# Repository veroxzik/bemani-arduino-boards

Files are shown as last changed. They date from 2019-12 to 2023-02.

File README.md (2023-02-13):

# bemani-arduino-boards
 A collection of Arduuino breakout boards and code for Bemani uses.

## How to Order

Download the *.zip file from your chosen Boards/gerbers folder and upload to your PCB manufacturer of choice. JLCPCB is a common suggestion and the one I use most frequently. Default choices are all acceptable.

A list of parts for each board is located in their respective folders.

## Physical Settings on the Boards

Each board has a few physical solder jumpers that you must set before use.

### Setting the lights power source

Locate the jumper labeled CNR PWR | USB PWR. If you wish to power the lights off of USB power, jump the center pad and the USB PWR pad together.

If you wish to use the external power header, jump the center pad and the CNR PWR pad together. All external power headers are such that the square pin is positive.

On several boards, it is necessary to select whether you want to use encoders or buttons. Such option is used by soldering the *two* jumpers between either BUT or ENC.

On the Micro boards, if you use one encoder, it must be QE2. On the Pro Micro board, it must be QE1. (Or you can change my code if you don't like this restriction.)

## How to Flash Firmware

### Load the board profile

Move the folder `Additional Files\arduino-bemani` to your local hardware folder, most commonly located at `Documents\Arduino\hardware\`.
Your final path should look like `Documents\Arduino\hardware\arduino-bemani`.

Start the Arduino IDE / restart if it's already open.

This uses a copy of the Arduino 1.8.1 core, for reference. You should not have to update it.

### Loading the firmware

In the Arduino IDE, select the board using `Tools->Board->Bemani Controller (Micro/Pro Micro)` under the `VXZK Custom Boards` section.

In `Config.h`, set the following parameters per your board and setup.

```c
/* --- --- --- --- --- --- ---
   Frequently Changed Settings
   --- --- --- --- --- --- --- */

// This is the number of encoders you are using.
// If it is 1 and you are using a Micro board, then you must use QE2.
// If it is 1 and you are using a Pro Micro board, then you must use QE1
#define NUM_ENCODERS 0

// This is the PPR of your encoder
// Common values are 600 for Chinese encoders and 24 for Bourns encoders
const uint16_t pulseCount = 24;

// Uncomment the corresponding define for the microcontroller you are using
//#define USE_PROMICRO
//#define USE_MICRO
```

You must uncomment either the USE_PROMICRO or USE_MICRO define or the compiler will throw an error.

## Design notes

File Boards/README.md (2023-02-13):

# Board Selection

Use the following guide to help you figure out which board suits your purposes.

These boards are designed for quadrature encoders. They *do not* support potentiometers.

## Micro Breakout

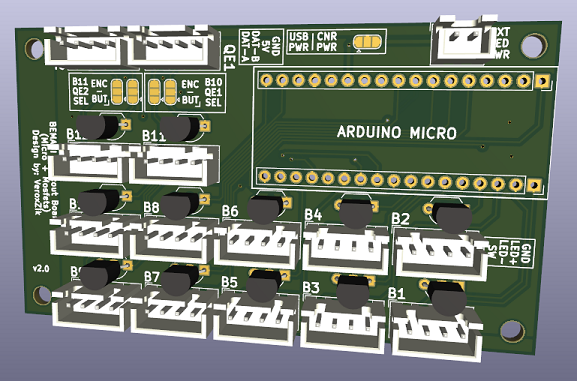
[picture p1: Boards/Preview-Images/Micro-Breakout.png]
Micro Breakout Board Image


This board uses the Arduino Micro as its base and supports 4 pin button connectors using the DJ DAO layout.

It is configurable for one of the three options:
1. 12 buttons, no encoders
2. 11 buttons, 1 encoder
3. 10 buttons, 2 encoders

## Micro Breakout + RGB

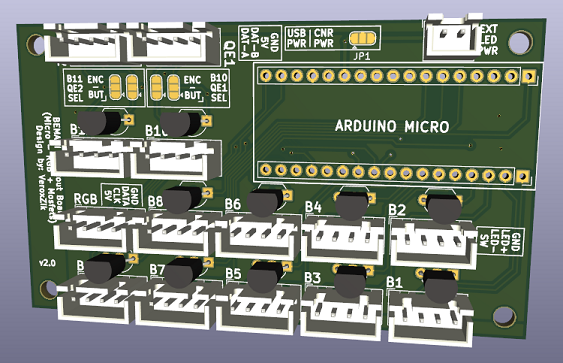
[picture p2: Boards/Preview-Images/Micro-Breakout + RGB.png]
Micro Breakout + RGB Board Image


This board uses the Arduino Micro as its base and supports 4 pin button connectors using the DJ DAO layout.

It is configurable for one of the three options:
1. 11 buttons, no encoders
2. 10 buttons, 1 encoder
3. 9 buttons, 2 encoders

In addition, there is a header for ARGB leds (WS2812B or APA102).

## ProMicro Breakout

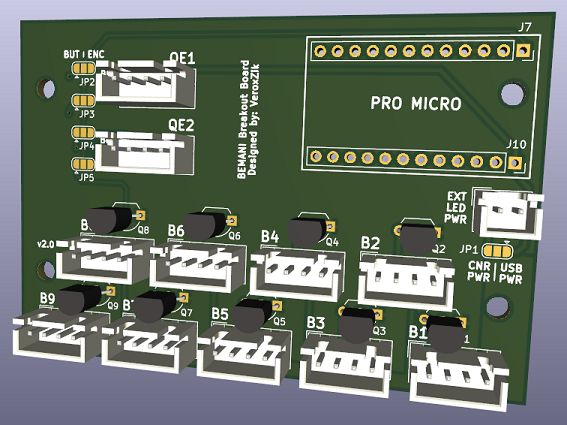
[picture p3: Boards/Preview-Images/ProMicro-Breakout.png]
ProMicro Breakout Board Image


This board uses the Sparkfun Pro Micro as its base and supports 4 pin button connectors using the DJ DAO layout.

It is configurable for one of the three options:
1. 9 buttons, no encoders
2. 8 buttons, 1 encoder
3. 7 buttons, 2 encoders

## ProMicro Breakout + RGB

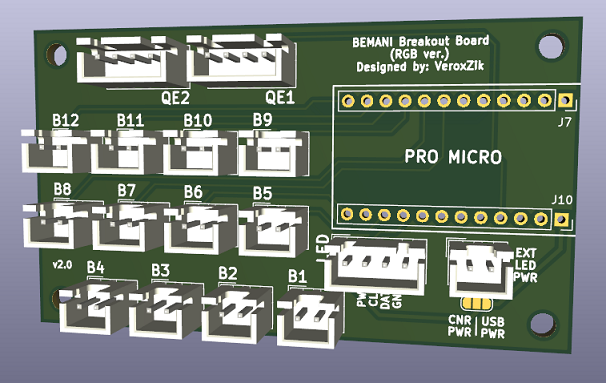
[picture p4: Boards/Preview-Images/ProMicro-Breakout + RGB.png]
ProMicro Breakout + RGB Board Image


This board uses the Sparkfun Pro Micro as its base and supports 2 pin buttons. It does not support button LEDs.

It supports 12 buttons and 2 encoders.

In addition, there is a header for ARGB leds (WS2812B or APA102).

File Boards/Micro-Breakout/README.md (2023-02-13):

# Micro Breakout

Micro Breakout Board Image

## Description

This board uses the Arduino Micro as its base and supports 4 pin button connectors using the DJ DAO layout.

It is configurable for one of the three options:
1. 12 buttons, no encoders
2. 11 buttons, 1 encoder
3. 10 buttons, 2 encoders

## Bill of Materials

| Part | Description | Qty | Link |
|:---|:---|:---:|:---|
| Arduino Micro | Microprocessor | 1 | Search "Arduino Micro" on Aliexpress, ensure the listing says 32U4. Example listing: https://www.aliexpress.us/item/2251801707415032.html |
| JST XH 4P Header | Connector for buttons, encoders, and RGB | 14 | https://www.lcsc.com/product-detail/Wire-To-Board-Wire-To-Wire-Connector_BOOMELE-Boom-Precision-Elec-XH-4A_C37815.html |
| 2N7000 | MOSFET 60V 0.2A N-Channel TO-92 | 12 | https://www.lcsc.com/product-detail/MOSFETs_Jiangsu-Changjing-Electronics-Technology-Co-Ltd-2N7000_C9114.html |
| JST XH 2P Header | Connector for external power (optional) | 1 (optional) | https://www.lcsc.com/product-detail/Wire-To-Board-Wire-To-Wire-Connector_BOOMELE-Boom-Precision-Elec-XH-2A_C20079.html |

Connectors can also be found on Aliexpress by searching "JST XH".

## Configuration

### Power Selection

Typically, you will be using USB power for this board. Solder the middle and left pads together on jumper located at the top of the board.

By soldering the other two pads, the LEDs will be powered via the JST XH 2P connector. This can allow you to use 12V leds, if this is desired.

### Button and Encoder Selection

Next to each QE connector is a pair of solder jumpers.

To use QE1, solder the middle and top pads together for the marked jumpers. Otherwise, solder the middle and bottom pads to use Button 10.

To use QE2, solder the middle and top pads together for the marked jumpers. Otherwise, solder the middle and bottom pads to use Button 11.

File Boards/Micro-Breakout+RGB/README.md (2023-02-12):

# Micro Breakout + RGB

Micro Breakout + RGB Board Image

## Description

This board uses the Arduino Micro as its base and supports 4 pin button connectors using the DJ DAO layout. There is one header for ARGB leds.

It is configurable for one of the three options:
1. 11 buttons, no encoders
2. 10 buttons, 1 encoder
3. 9 buttons, 2 encoders

## Bill of Materials

| Part | Description | Qty | Link |
|:---|:---|:---:|:---|
| Arduino Micro | Microprocessor | 1 | Search "Arduino Micro" on Aliexpress, ensure the listing says 32U4. Example listing: https://www.aliexpress.us/item/2251801707415032.html |
| JST XH 4P Header | Connector for buttons, encoders, and RGB | 14 | https://www.lcsc.com/product-detail/Wire-To-Board-Wire-To-Wire-Connector_BOOMELE-Boom-Precision-Elec-XH-4A_C37815.html |
| JST XH 2P Header | Connector for external power (optional) | 1 (optional) | https://www.lcsc.com/product-detail/Wire-To-Board-Wire-To-Wire-Connector_BOOMELE-Boom-Precision-Elec-XH-2A_C20079.html |
| 2N7000 | MOSFET 60V 0.2A N-Channel TO-92 | 11 | https://www.lcsc.com/product-detail/MOSFETs_Jiangsu-Changjing-Electronics-Technology-Co-Ltd-2N7000_C9114.html |

Connectors can also be found on Aliexpress by searching "JST XH".

## Configuration

### Power Selection

Typically, you will be using USB power for this board. Solder the middle and left pads together on jumper JP1.

By soldering the other two pads, the LEDs will be powered via the JST XH 2P connector. This can allow you to use 12V leds, if this is desired.

### Button and Encoder Selection

Next to each QE connector is a pair of solder jumpers.

To use QE1, solder the middle and top pads together for the marked jumpers. Otherwise, solder the middle and bottom pads to use Button 10.

To use QE2, solder the middle and top pads together for the marked jumpers. Otherwise, solder the middle and bottom pads to use Button 11.

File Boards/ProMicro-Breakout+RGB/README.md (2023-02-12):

# ProMicro Breakout + RGB

ProMicro Breakout + RGB Board Image

## Description

This board is just for the bare essentials, providing 12 buttons (WITHOUT lights), 2 quadrature encoder inputs, and 1 ARGB header.

## Bill of Materials

| Part | Description | Qty | Link |
|:---|:---|:---:|:---|
| Arduino Pro Micro | Microprocessor | 1 | Search "Pro Micro" on Aliexpress, ensure the listing says 32U4 |
| JST XH 2P Header | Connector for buttons and power (optional) | 12 (+ 1 optional) | https://www.lcsc.com/product-detail/Wire-To-Board-Wire-To-Wire-Connector_BOOMELE-Boom-Precision-Elec-XH-2A_C20079.html |
| JST XH 4P Header | Connector for encoder and RGB | 3 | https://www.lcsc.com/product-detail/Wire-To-Board-Wire-To-Wire-Connector_BOOMELE-Boom-Precision-Elec-XH-4A_C37815.html |

Connectors can also be found on Aliexpress by searching "JST XH".

## Configuration

### Power Selection

Typically, you will be using USB power for this board. Solder the middle and right pads together on jumper JP1.

By soldering the other two pads, the LEDs will be powered via the JST XH 2P connector. This can allow you to use 12V leds, if this is desired.

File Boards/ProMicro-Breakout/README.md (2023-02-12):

# ProMicro Breakout

ProMicro Breakout Board Image

## Description

This board uses the Sparkfun Pro Micro as its base and supports 4 pin button connectors using the DJ DAO layout.

It is configurable for one of the three options:
1. 9 buttons, no encoders
2. 8 buttons, 1 encoder
3. 7 buttons, 2 encoders

## Bill of Materials

| Part | Description | Qty | Link |
|:---|:---|:---:|:---|
| Arduino Pro Micro | Microprocessor | 1 | Search "Pro Micro" on Aliexpress, ensure the listing says 32U4 |
| JST XH 4P Header | Connector for buttons and encoder | 11 | https://www.lcsc.com/product-detail/Wire-To-Board-Wire-To-Wire-Connector_BOOMELE-Boom-Precision-Elec-XH-4A_C37815.html |
| JST XH 2P Header | Connector for external power (optional) | 1 (optional) | https://www.lcsc.com/product-detail/Wire-To-Board-Wire-To-Wire-Connector_BOOMELE-Boom-Precision-Elec-XH-2A_C20079.html |
| 2N7000 | MOSFET 60V 0.2A N-Channel TO-92 | 9 | https://www.lcsc.com/product-detail/MOSFETs_Jiangsu-Changjing-Electronics-Technology-Co-Ltd-2N7000_C9114.html |

Connectors can also be found on Aliexpress by searching "JST XH".

## Configuration

### Power Selection

Typically, you will be using USB power for this board. Solder the middle and right pads together on jumper JP1.

By soldering the other two pads, the LEDs will be powered via the JST XH 2P connector. This can allow you to use 12V leds, if this is desired.

### Button and Encoder Selection

Next to each QE connector is a pair of solder jumpers.

To use QE1, solder the middle and right pads together for jumpers JP2 and JP3. Otherwise, solder the middle and left pads to use Button 9.

To use QE2, solder the middle and right pads together for jumpers JP4 and JP5. Otherwise, solder the middle and left pads to use Button 8.

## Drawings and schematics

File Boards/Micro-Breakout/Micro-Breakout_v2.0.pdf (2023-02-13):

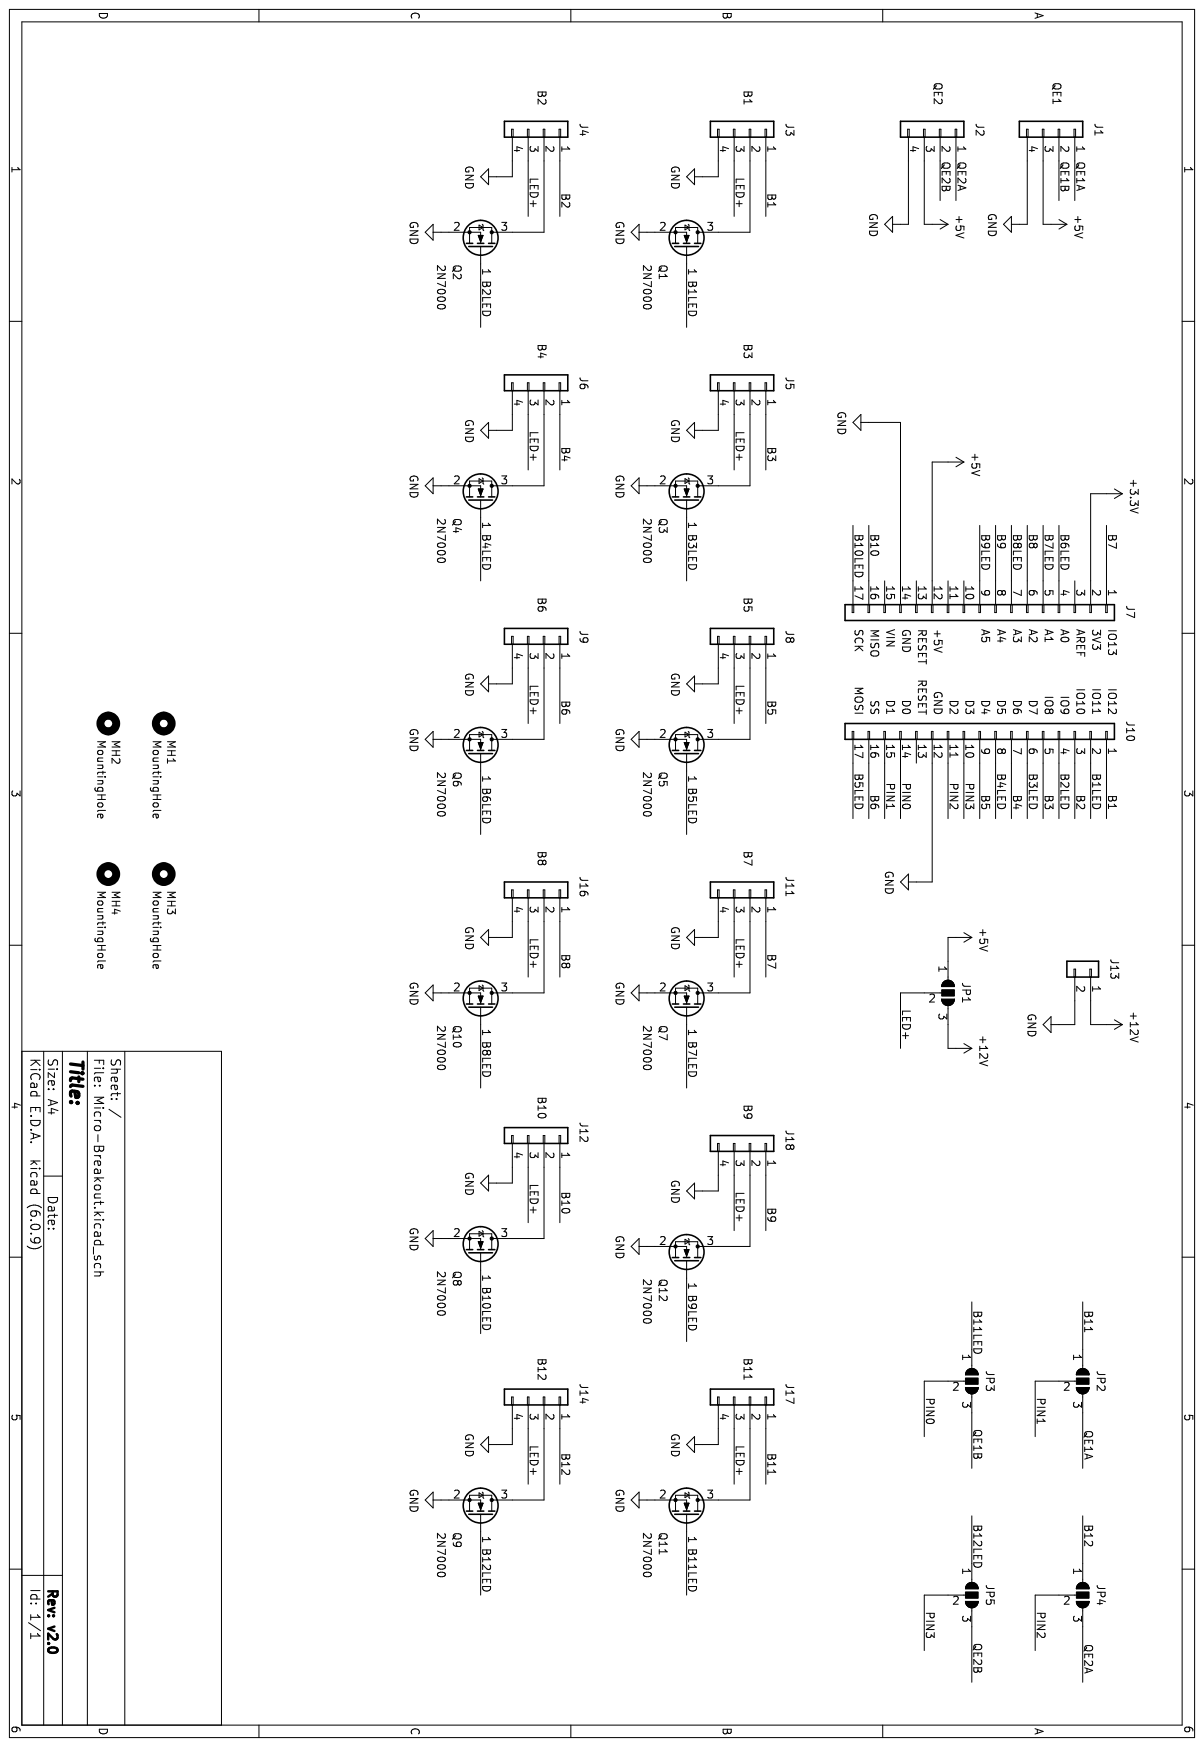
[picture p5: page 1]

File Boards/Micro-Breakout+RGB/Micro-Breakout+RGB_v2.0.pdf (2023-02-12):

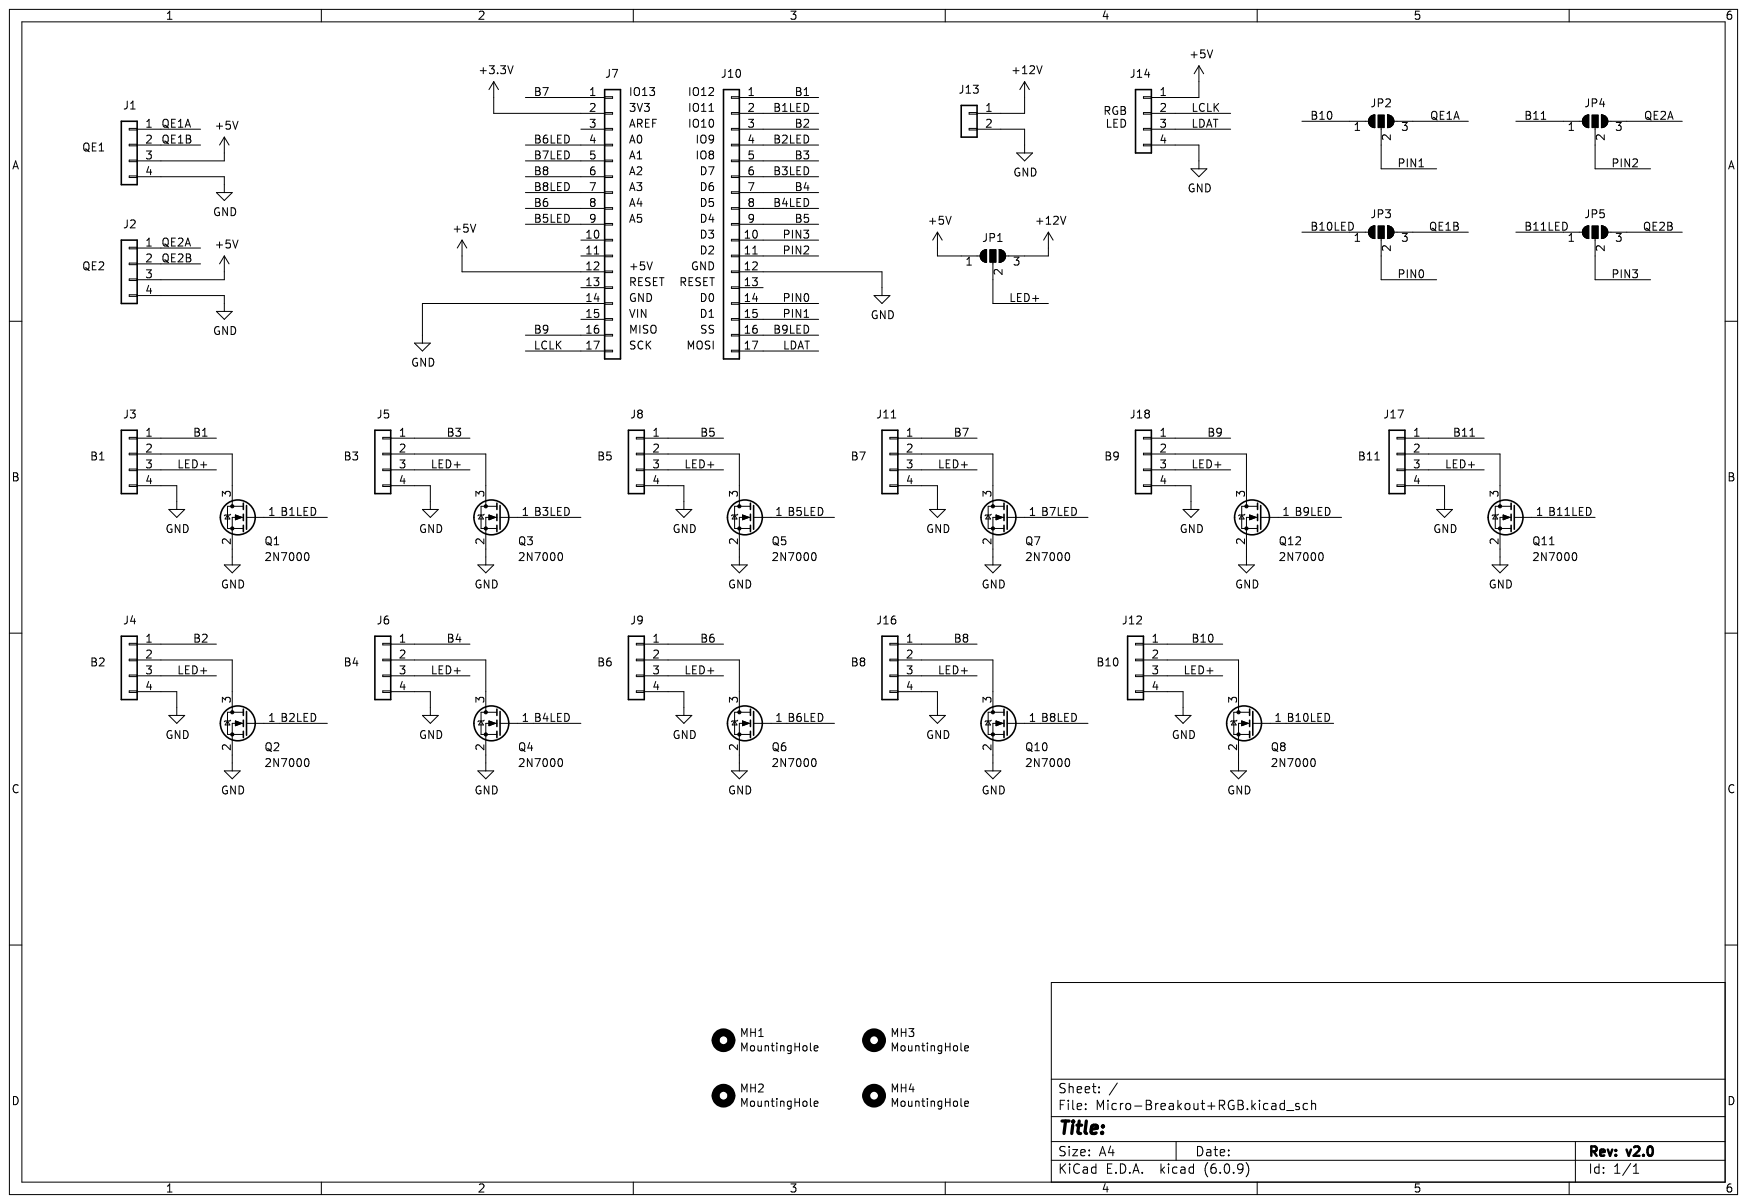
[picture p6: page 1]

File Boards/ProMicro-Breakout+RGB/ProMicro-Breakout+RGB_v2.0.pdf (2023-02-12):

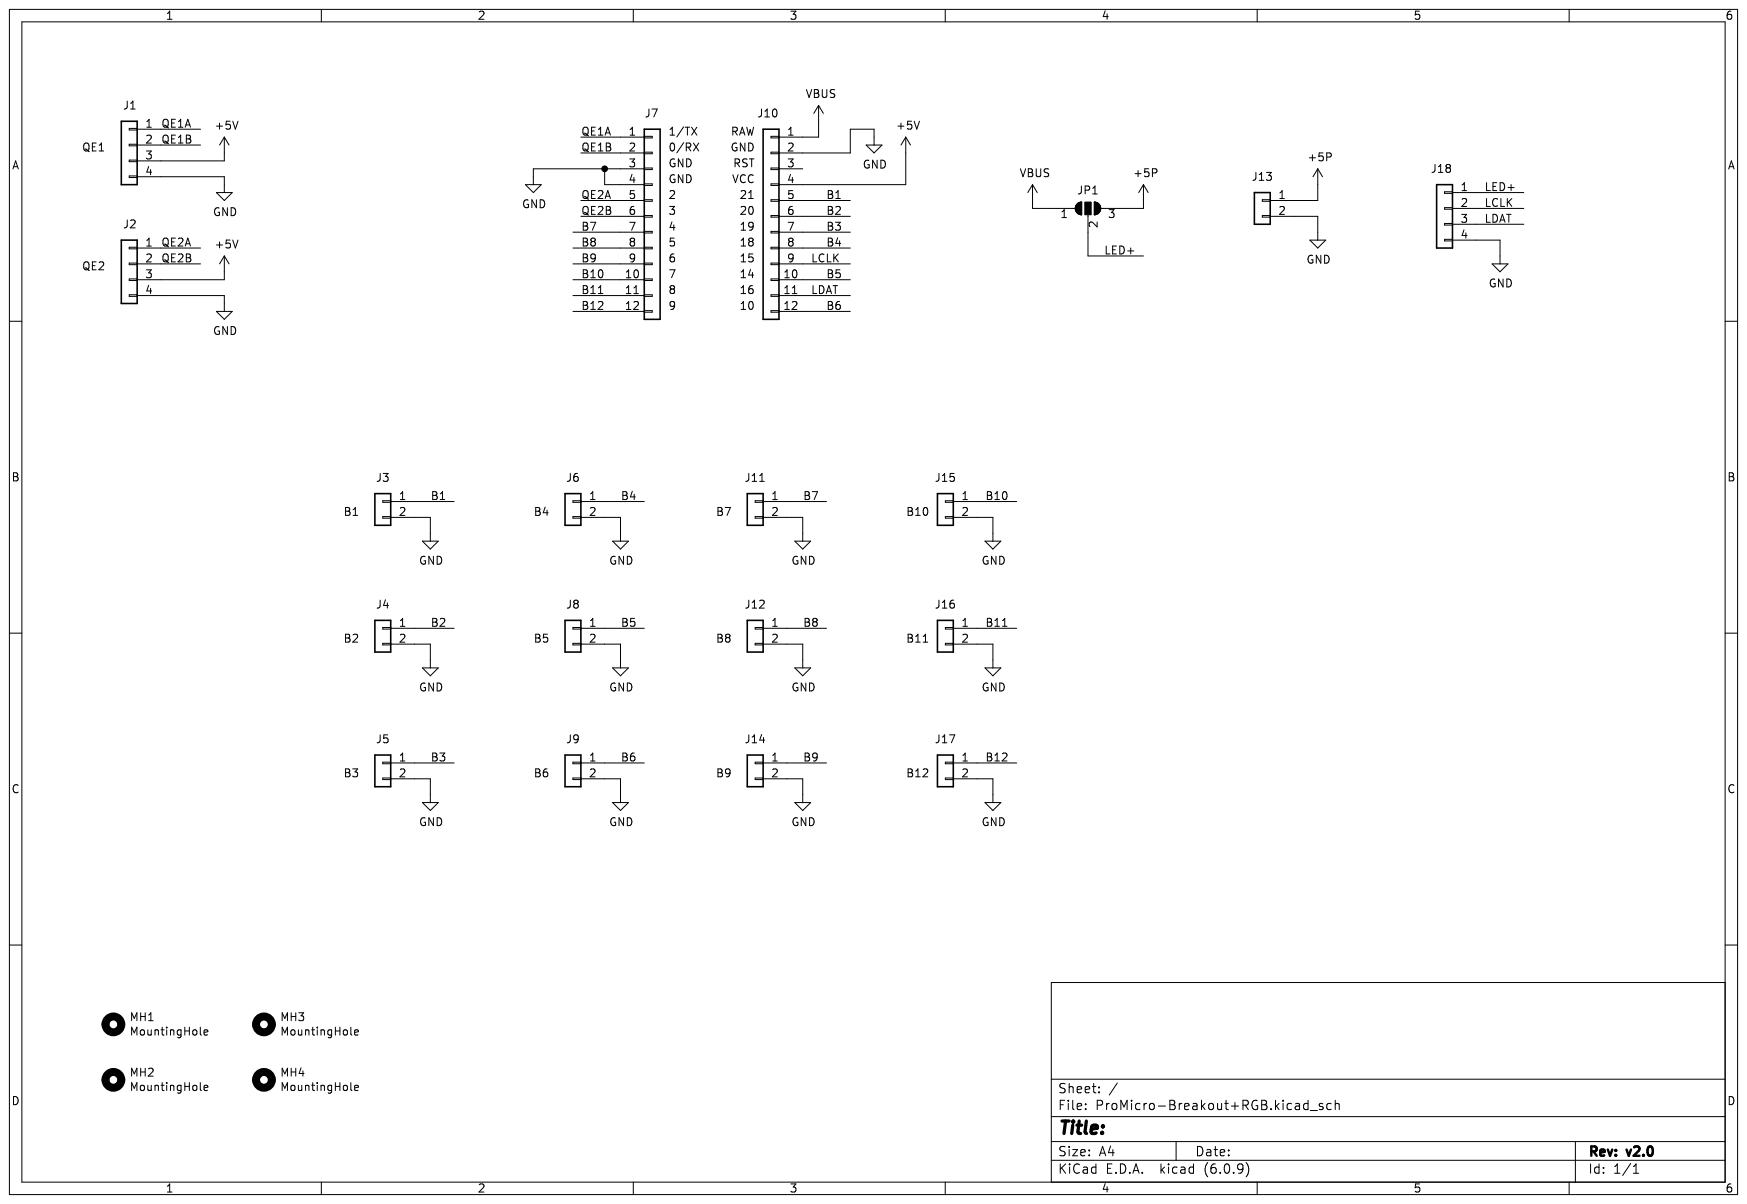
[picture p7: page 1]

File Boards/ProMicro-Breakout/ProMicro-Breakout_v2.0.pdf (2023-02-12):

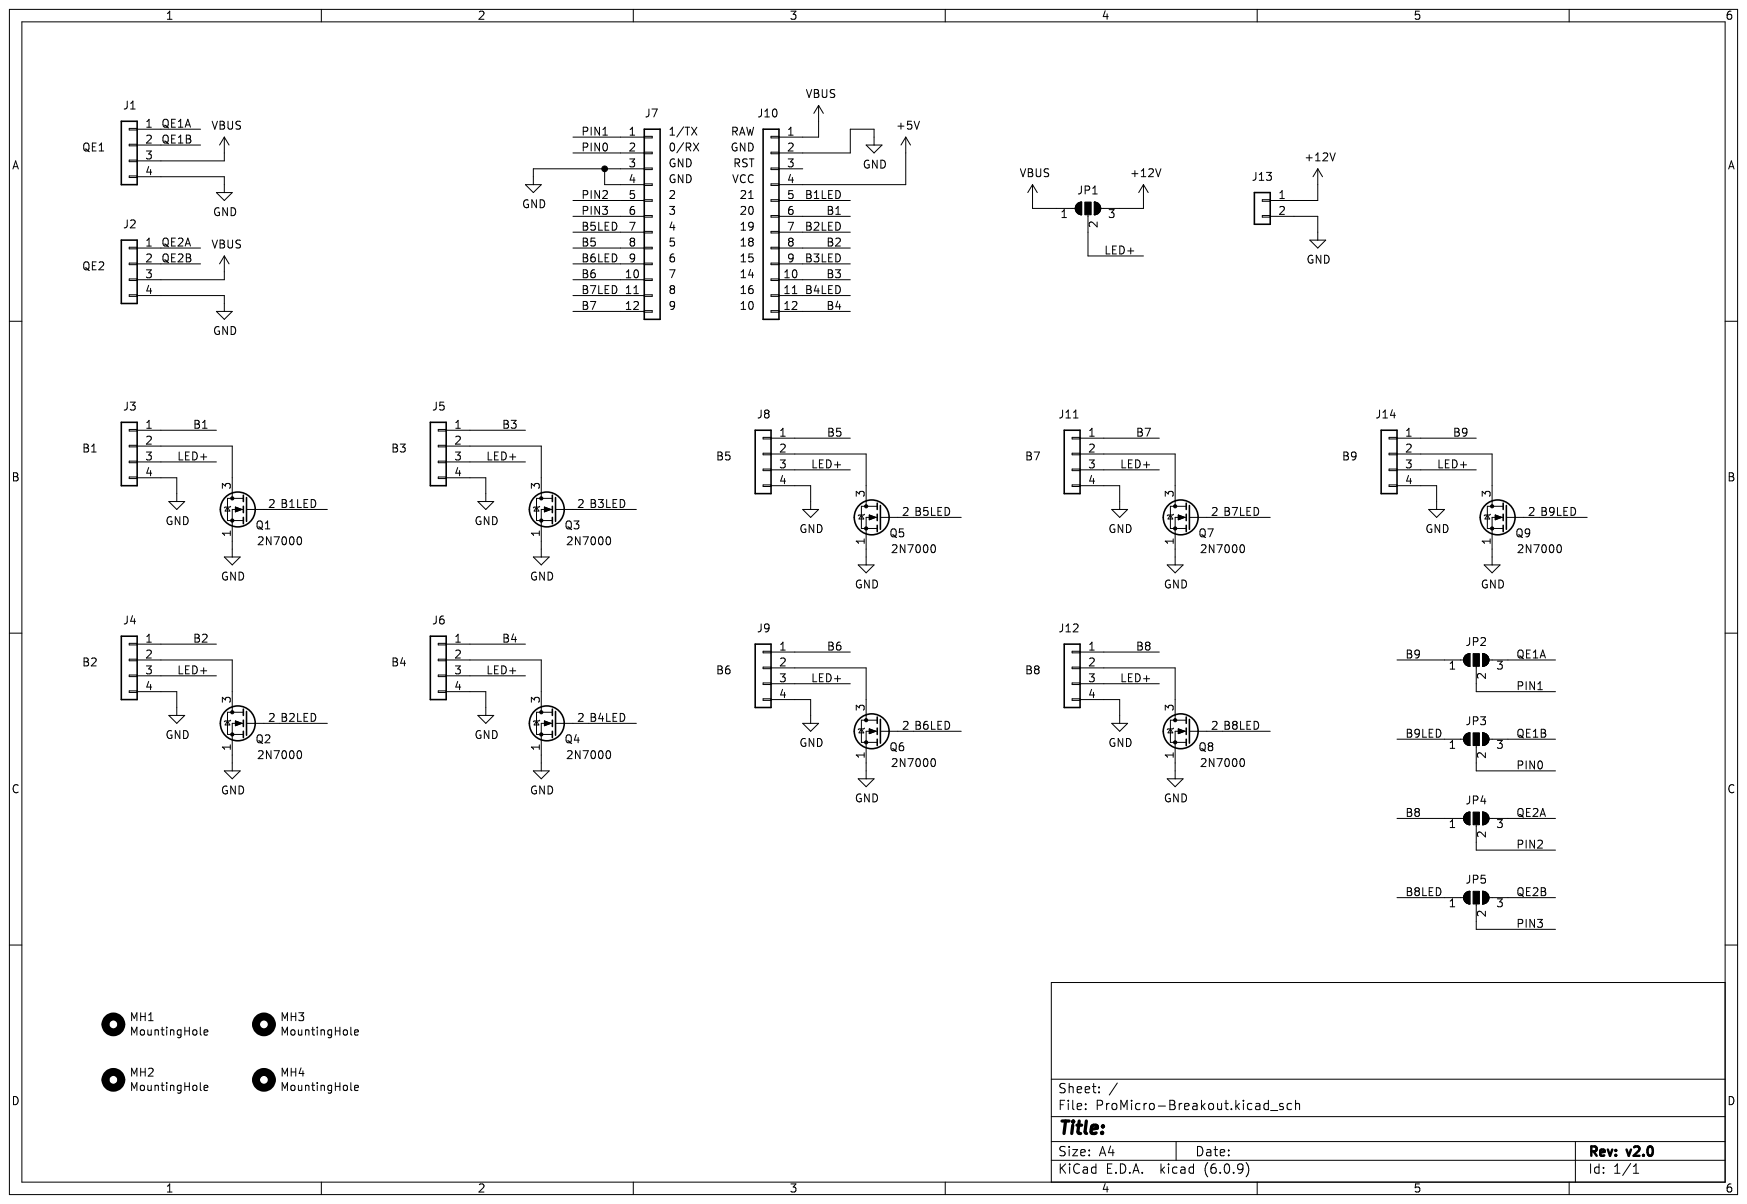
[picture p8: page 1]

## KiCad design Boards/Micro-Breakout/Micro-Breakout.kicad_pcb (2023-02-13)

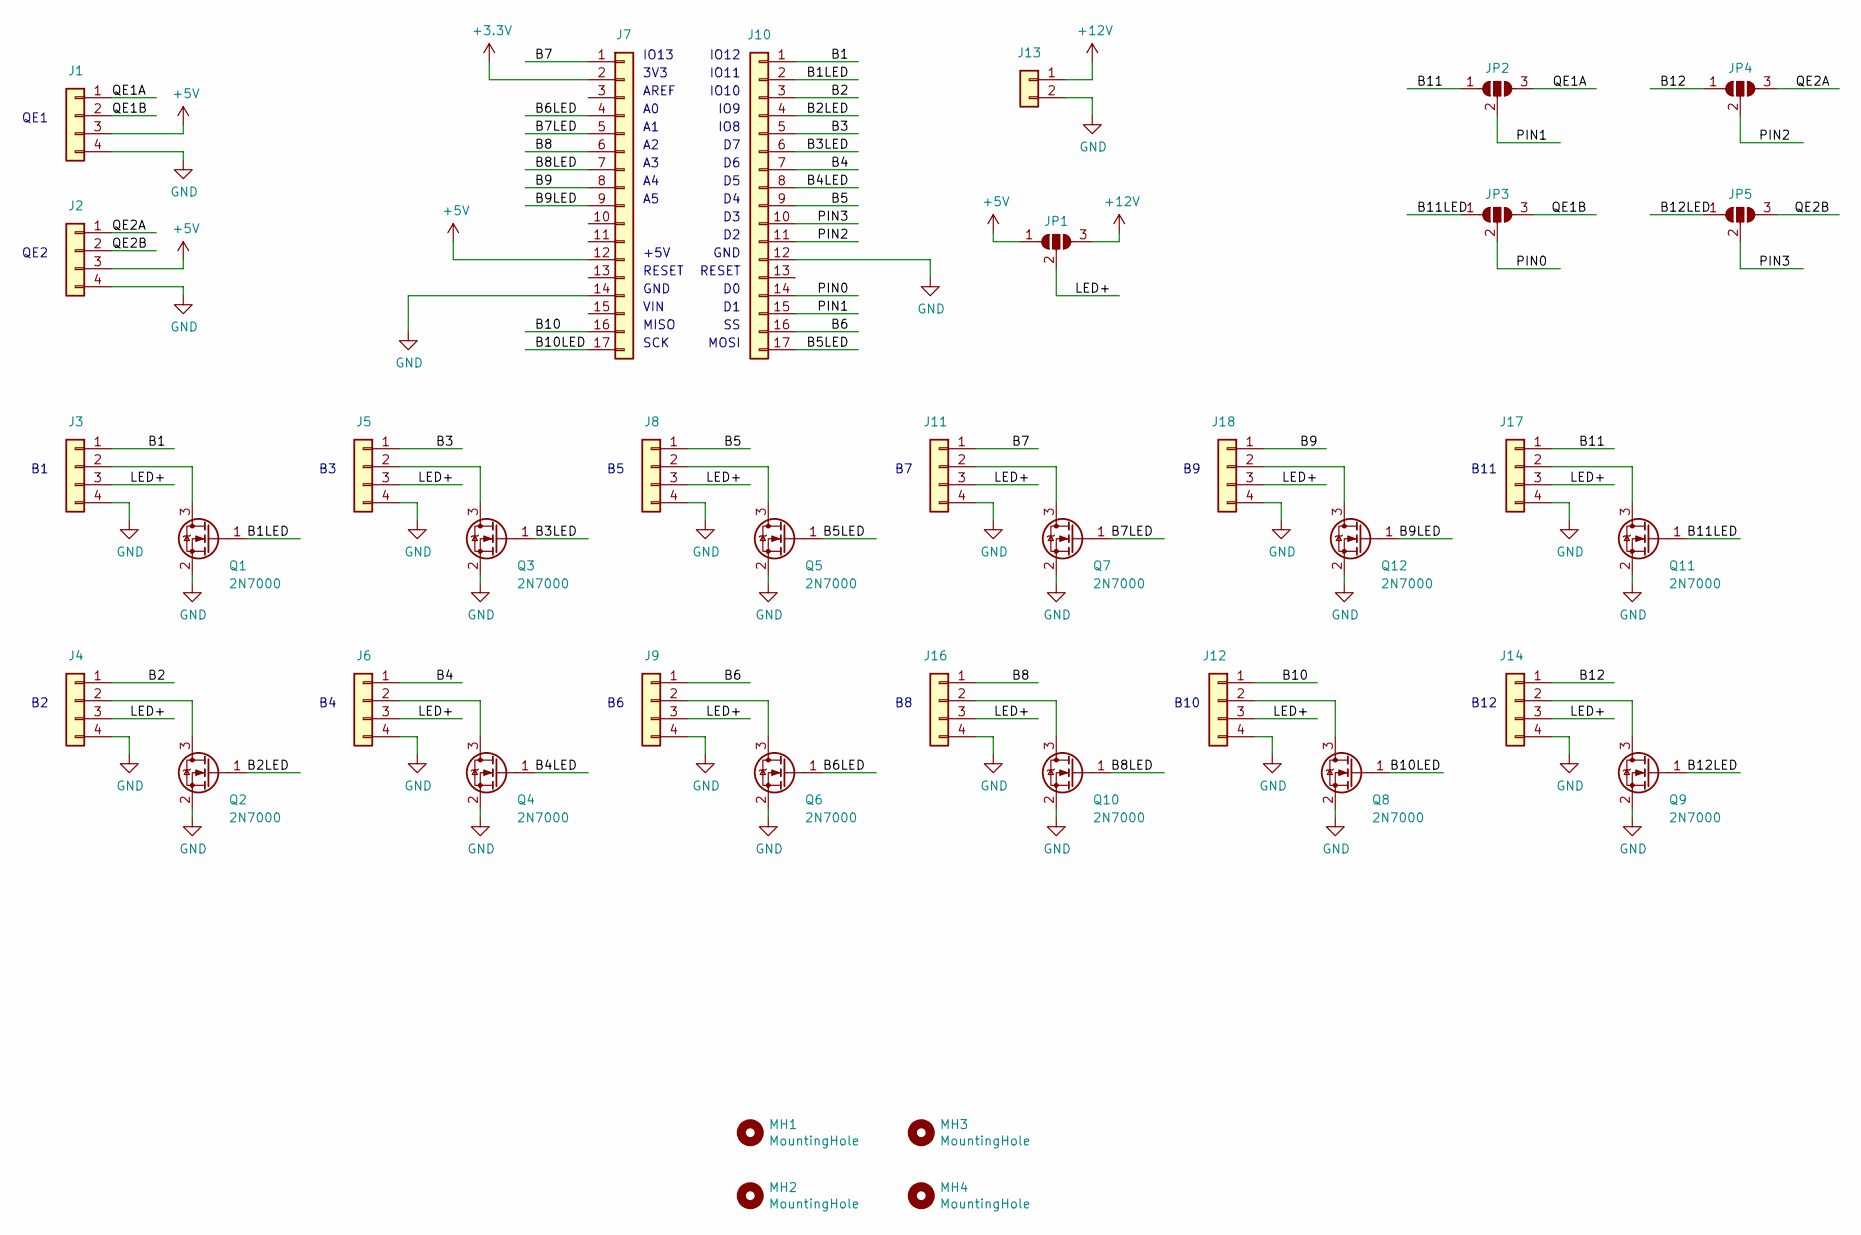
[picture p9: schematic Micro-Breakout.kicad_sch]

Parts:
J1, J2, J3, J4, J5, J6, J8, J9, J11, J12, J14, J16, J17, J18: Conn_01x04; JST_XH_B4B-XH-A_1x04_P2.50mm_Vertical
J7, J10: Conn_01x17; PinSocket_1x17_P2.54mm_Vertical
J13: Conn_01x02; JST_XH_B2B-XH-A_1x02_P2.50mm_Vertical
JP1, JP2, JP3, JP4, JP5: SolderJumper_3_Open; SolderJumper-3_P1.3mm_Open_RoundedPad1.0x1.5mm
MH1, MH2, MH3, MH4: MountingHole; MountingHole_3.2mm_M3
Q1, Q2, Q3, Q4, Q5, Q6, Q7, Q8, Q9, Q10, Q11, Q12: 2N7000; TO-92_Inline_Wide

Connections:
+3V3: J7.2
+5V: J1.3, J2.3, J7.12, JP1.1 (A)
+12V: J13.1, JP1.3 (B)
/B1: J3.1, J10.1
/B1LED: J10.2, Q1.1 (G)
/B2: J4.1, J10.3
/B2LED: J10.4, Q2.1 (G)
/B3: J5.1, J10.5
/B3LED: J10.6, Q3.1 (G)
/B4: J6.1, J10.7
/B4LED: J10.8, Q4.1 (G)
/B5: J8.1, J10.9
/B5LED: J10.17, Q5.1 (G)
/B6: J9.1, J10.16
/B6LED: J7.4, Q6.1 (G)
/B7: J7.1, J11.1
/B7LED: J7.5, Q7.1 (G)
/B8: J7.6, J16.1
/B8LED: J7.7, Q10.1 (G)
/B9: J7.8, J18.1
/B9LED: J7.9, Q12.1 (G)
/B10: J7.16, J12.1
/B10LED: J7.17, Q8.1 (G)
/B11: J17.1, JP2.1 (A)
/B11LED: JP3.1 (A), Q11.1 (G)
/B12: J14.1, JP4.1 (A)
/B12LED: JP5.1 (A), Q9.1 (G)
/LED+: J3.3, J4.3, J5.3, J6.3, J8.3, J9.3, J11.3, J12.3, J14.3, J16.3, J17.3, J18.3, JP1.2 (C)
/PIN0: J10.14, JP3.2 (C)
/PIN1: J10.15, JP2.2 (C)
/PIN2: J10.11, JP4.2 (C)
/PIN3: J10.10, JP5.2 (C)
/QE1A: J1.1, JP2.3 (B)
/QE1B: J1.2, JP3.3 (B)
/QE2A: J2.1, JP4.3 (B)
/QE2B: J2.2, JP5.3 (B)
GND: J1.4, J2.4, J3.4, J4.4, J5.4, J6.4, J7.14, J8.4, J9.4, J10.12, J11.4, J12.4, J13.2, J14.4, J16.4, J17.4, J18.4, Q1.2 (S), Q2.2 (S), Q3.2 (S), Q4.2 (S), Q5.2 (S), Q6.2 (S), Q7.2 (S), Q8.2 (S), Q9.2 (S), Q10.2 (S), Q11.2 (S), Q12.2 (S)
unnamed: J3.2, Q1.3 (D)
unnamed: J4.2, Q2.3 (D)
unnamed: J5.2, Q3.3 (D)
unnamed: J6.2, Q4.3 (D)
unnamed: J8.2, Q5.3 (D)
unnamed: J9.2, Q6.3 (D)
unnamed: J11.2, Q7.3 (D)
unnamed: J12.2, Q8.3 (D)
unnamed: J14.2, Q9.3 (D)
unnamed: J16.2, Q10.3 (D)
unnamed: J17.2, Q11.3 (D)
unnamed: J18.2, Q12.3 (D)

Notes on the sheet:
IO11
B12
QE1
QE2
VIN
GND
3V3
IO9
MOSI
+5V
RESET
MISO
SCK
IO8
IO13
B11
IO10
B10
IO12
AREF

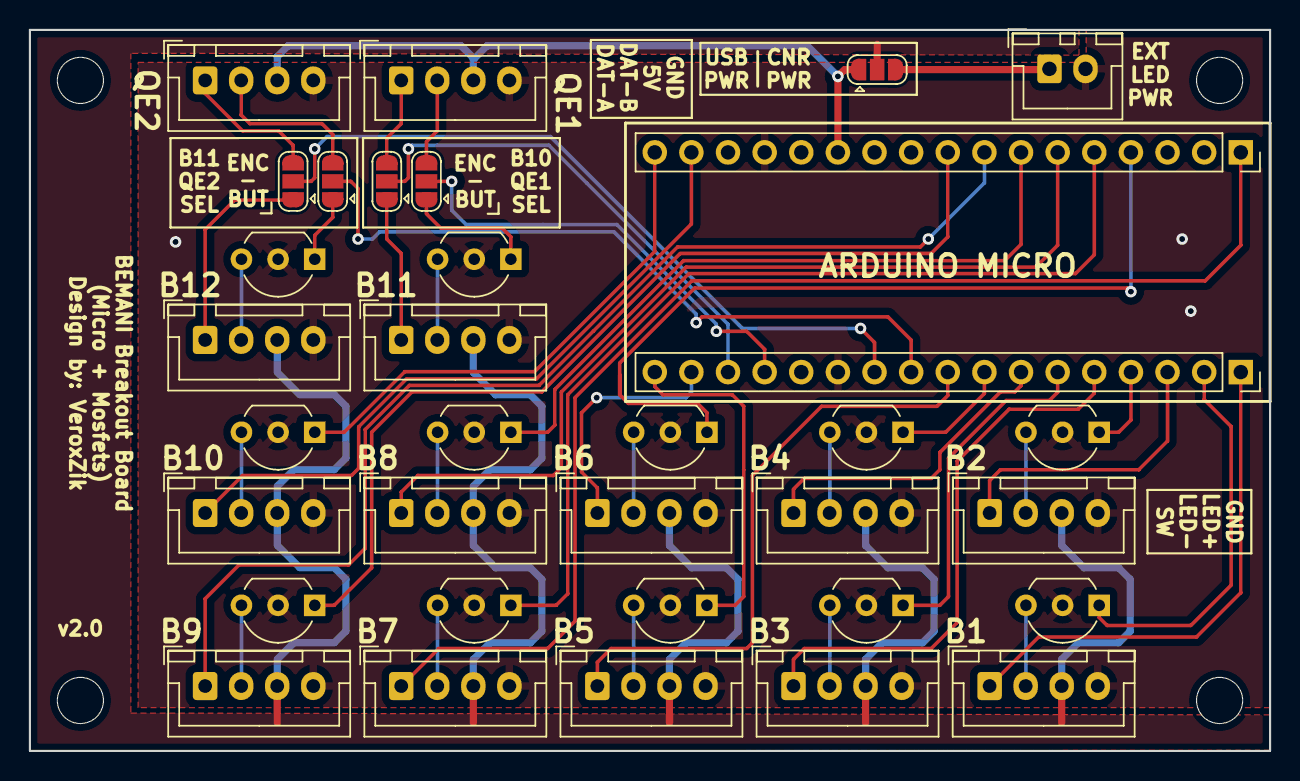
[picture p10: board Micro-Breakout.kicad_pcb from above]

Board: 2 copper layers, 86.0 x 50.0 mm, 38 parts (0 on the bottom side), 48 nets.

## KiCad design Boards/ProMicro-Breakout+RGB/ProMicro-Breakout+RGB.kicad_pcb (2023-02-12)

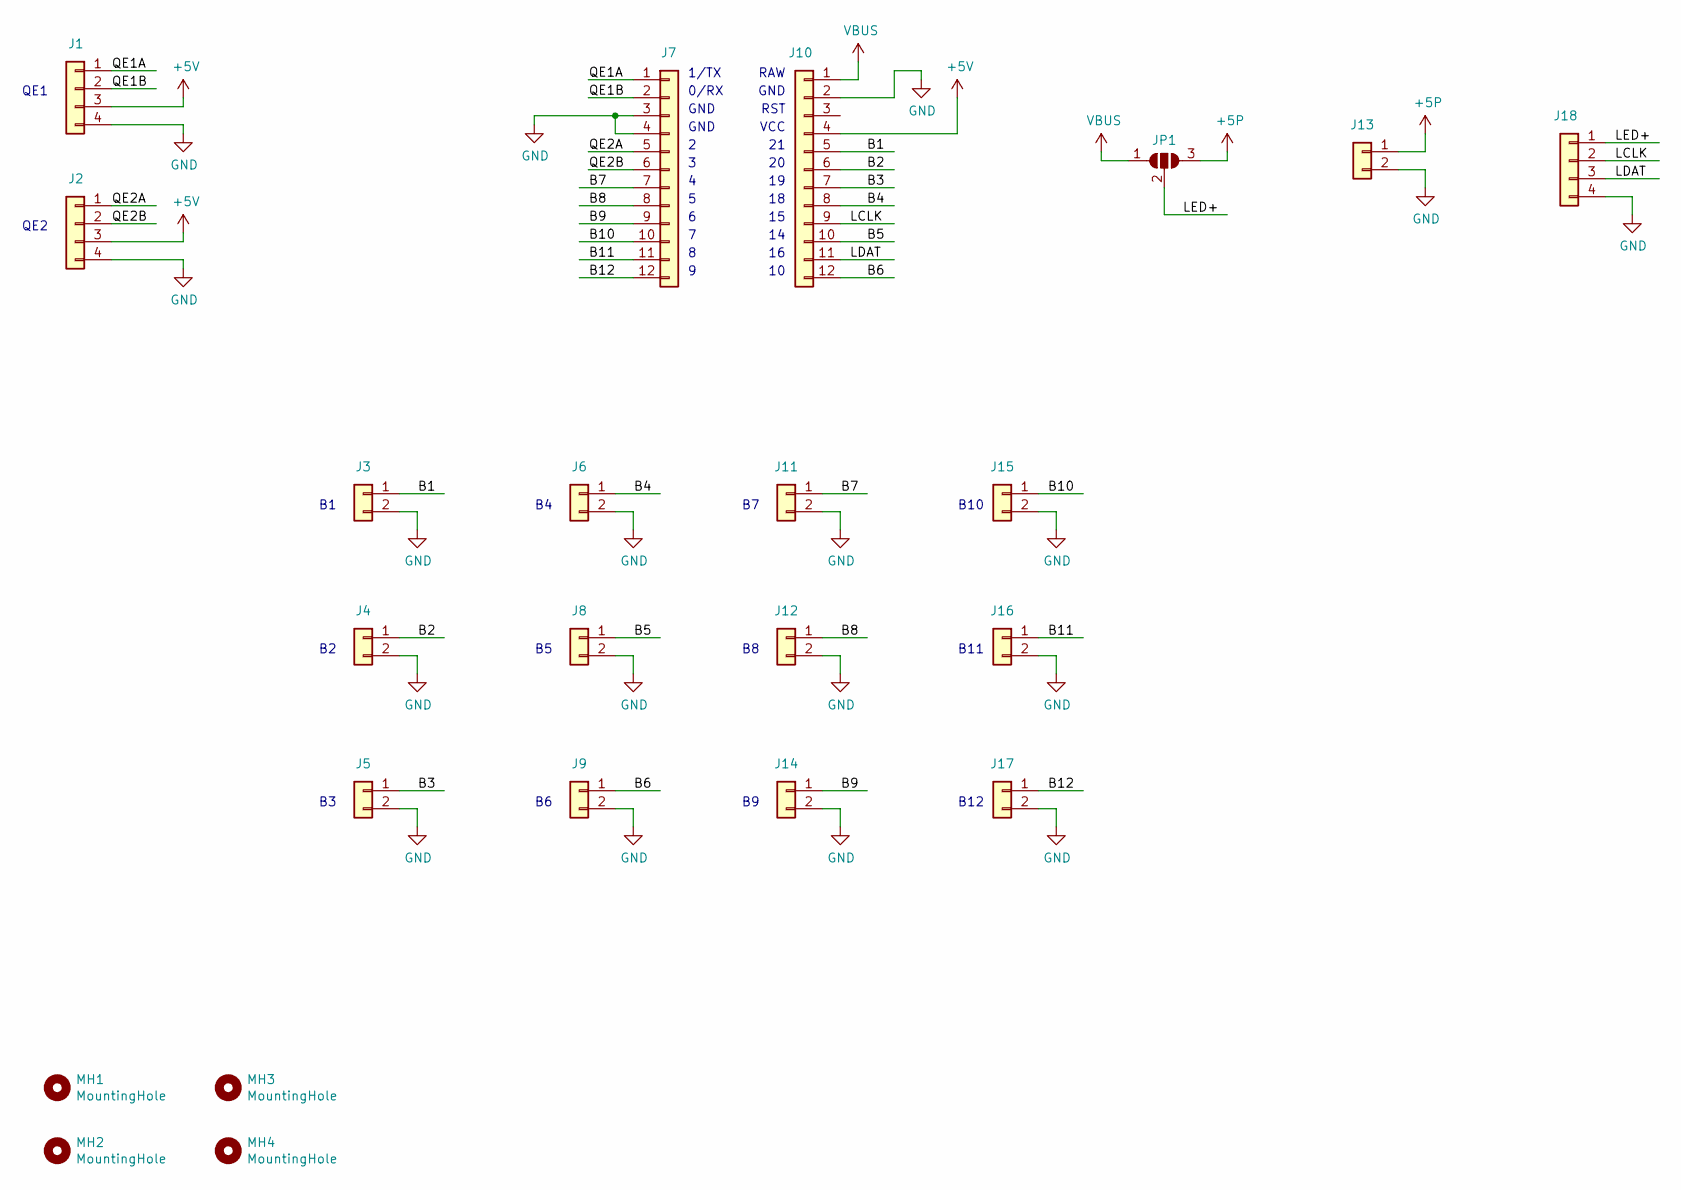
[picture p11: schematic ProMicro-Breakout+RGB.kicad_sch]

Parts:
J1, J2, J18: Conn_01x04; JST_XH_B04B-XH-A_04x2.50mm_Straight
J3, J4, J5, J6, J8, J9, J11, J12, J13, J14, J15, J16, J17: Conn_01x02; JST_XH_B02B-XH-A_02x2.50mm_Straight
J7, J10: Conn_01x12; PinSocket_1x12_P2.54mm_Vertical
JP1: SolderJumper_3_Open; SolderJumper-3_P1.3mm_Open_RoundedPad1.0x1.5mm
MH1, MH2, MH3, MH4: MountingHole; MountingHole_3.2mm_M3

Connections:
+5P: J13.1, JP1.3 (B)
+5V: J1.3, J2.3, J10.4
/B1: J3.1, J10.5
/B2: J4.1, J10.6
/B3: J5.1, J10.7
/B4: J6.1, J10.8
/B5: J8.1, J10.10
/B6: J9.1, J10.12
/B7: J7.7, J11.1
/B8: J7.8, J12.1
/B9: J7.9, J14.1
/B10: J7.10, J15.1
/B11: J7.11, J16.1
/B12: J7.12, J17.1
/LCLK: J10.9, J18.2
/LDAT: J10.11, J18.3
/LED+: J18.1, JP1.2 (C)
/QE1A: J1.1, J7.1
/QE1B: J1.2, J7.2
/QE2A: J2.1, J7.5
/QE2B: J2.2, J7.6
GND: J1.4, J2.4, J3.2, J4.2, J5.2, J6.2, J7.3, J7.4, J8.2, J9.2, J10.2, J11.2, J12.2, J13.2, J14.2, J15.2, J16.2, J17.2, J18.4
VBUS: J10.1, JP1.1 (A)

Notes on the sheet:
B12
QE2
B11
GND
B10
0/RX
VCC
QE1
1/TX
RST
RAW

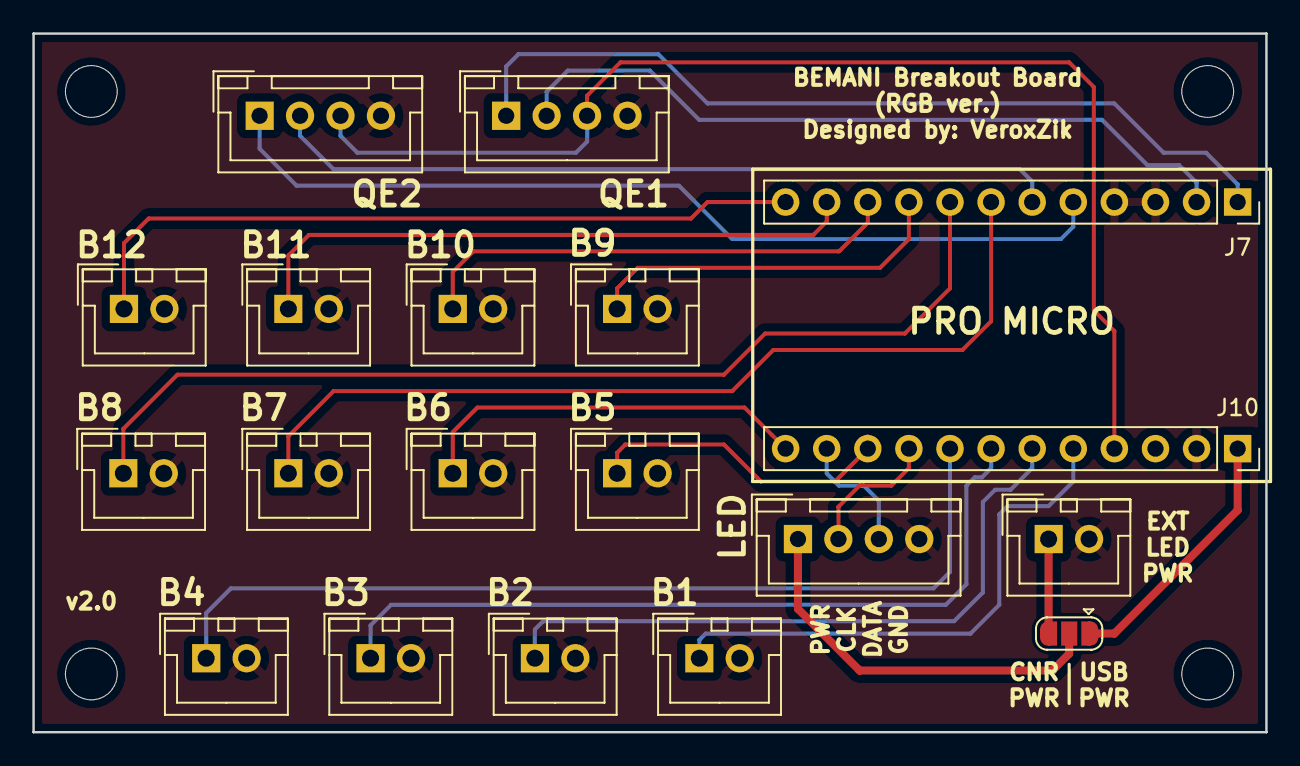
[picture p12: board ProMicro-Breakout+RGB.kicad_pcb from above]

Board: 2 copper layers, 76.2 x 43.2 mm, 23 parts (0 on the bottom side), 23 nets.

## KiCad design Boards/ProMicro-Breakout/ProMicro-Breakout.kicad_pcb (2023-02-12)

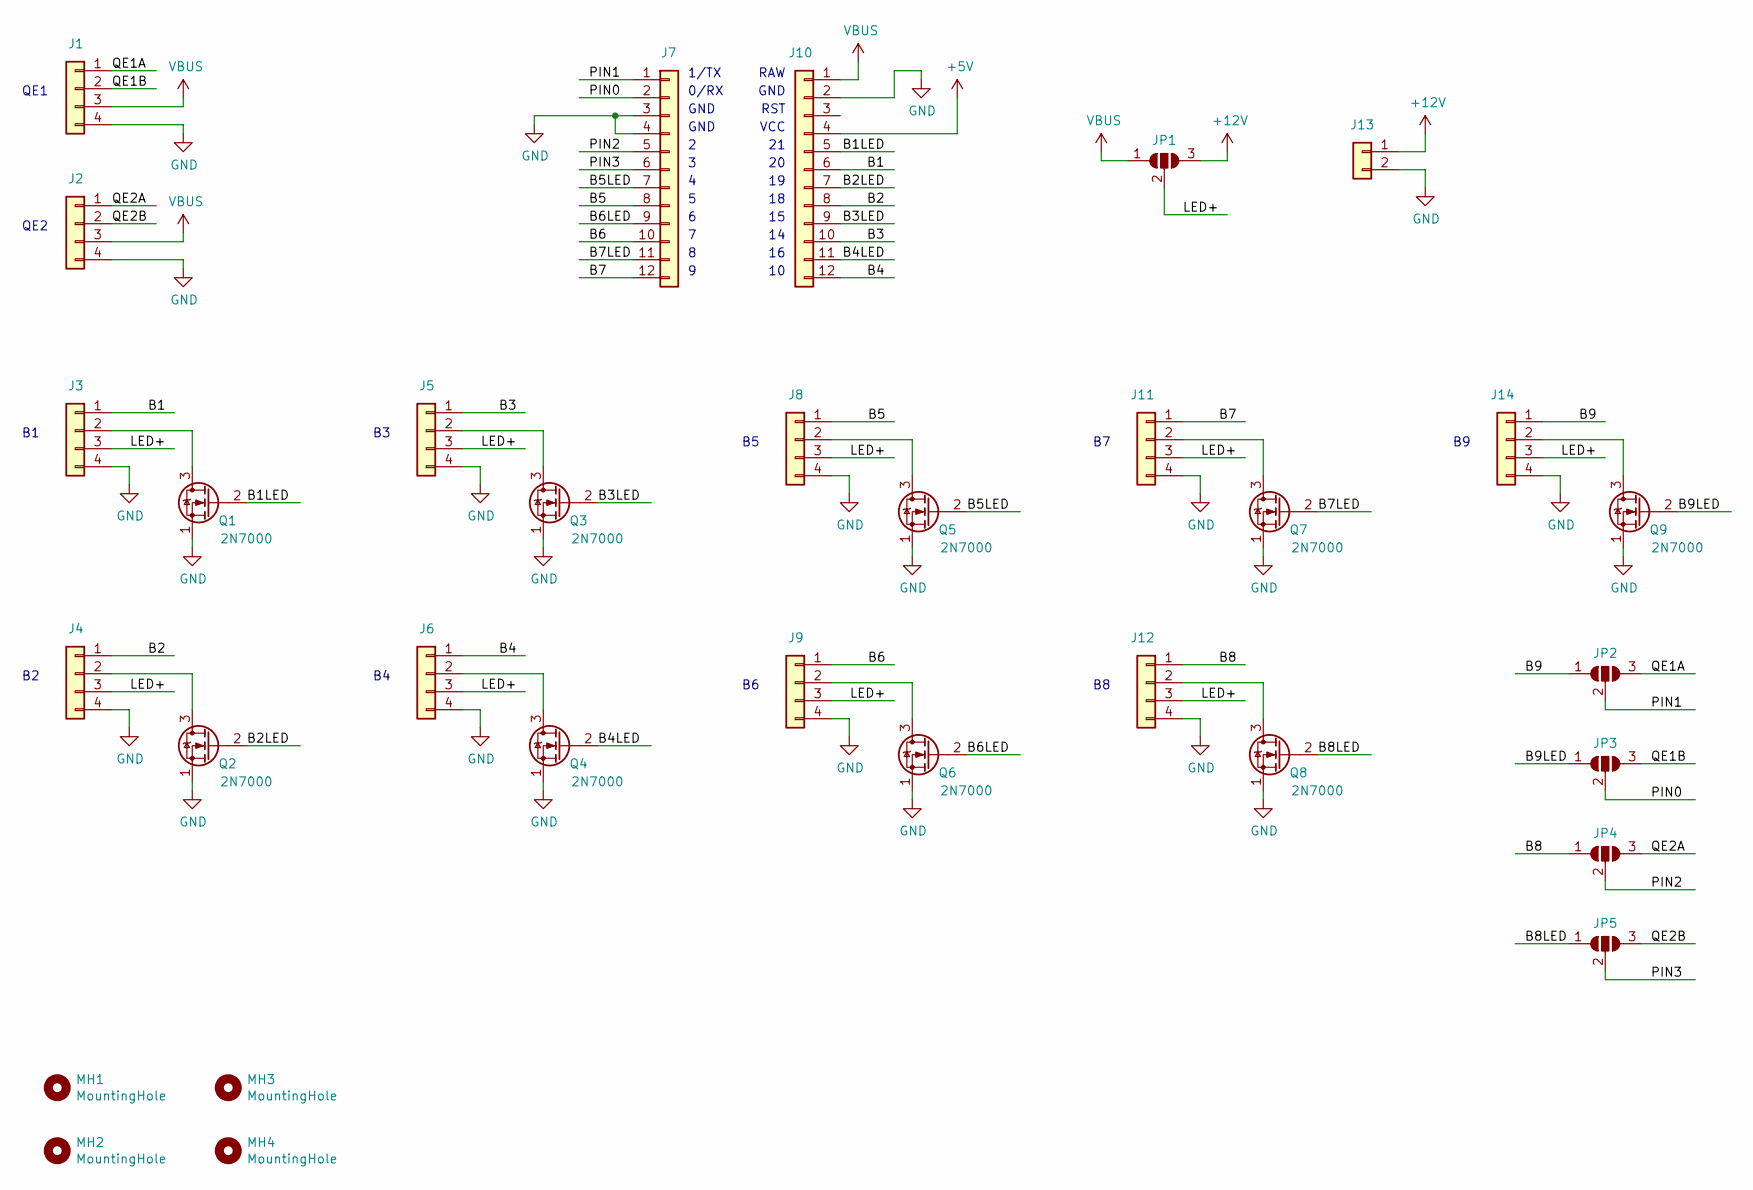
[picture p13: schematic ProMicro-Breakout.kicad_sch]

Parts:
J1, J2, J3, J4, J5, J6, J8, J9, J11, J12, J14: Conn_01x04; JST_XH_B04B-XH-A_04x2.50mm_Straight
J7, J10: Conn_01x12; PinSocket_1x12_P2.54mm_Vertical
J13: Conn_01x02; JST_XH_B02B-XH-A_02x2.50mm_Straight
JP1, JP2, JP3, JP4, JP5: SolderJumper_3_Open; SolderJumper-3_P1.3mm_Open_RoundedPad1.0x1.5mm
MH1, MH2, MH3, MH4: MountingHole; MountingHole_3.2mm_M3
Q1, Q2, Q3, Q4, Q5, Q6, Q7, Q8, Q9: 2N7000; TO-92_Inline_Wide

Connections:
+5V: J10.4
+12V: J13.1, JP1.3 (B)
/B1: J3.1, J10.6
/B1LED: J10.5, Q1.2 (G)
/B2: J4.1, J10.8
/B2LED: J10.7, Q2.2 (G)
/B3: J5.1, J10.10
/B3LED: J10.9, Q3.2 (G)
/B4: J6.1, J10.12
/B4LED: J10.11, Q4.2 (G)
/B5: J7.8, J8.1
/B5LED: J7.7, Q5.2 (G)
/B6: J7.10, J9.1
/B6LED: J7.9, Q6.2 (G)
/B7: J7.12, J11.1
/B7LED: J7.11, Q7.2 (G)
/B8: J12.1, JP4.1 (A)
/B8LED: JP5.1 (A), Q8.2 (G)
/B9: J14.1, JP2.1 (A)
/B9LED: JP3.1 (A), Q9.2 (G)
/LED+: J3.3, J4.3, J5.3, J6.3, J8.3, J9.3, J11.3, J12.3, J14.3, JP1.2 (C)
/PIN0: J7.2, JP3.2 (C)
/PIN1: J7.1, JP2.2 (C)
/PIN2: J7.5, JP4.2 (C)
/PIN3: J7.6, JP5.2 (C)
/QE1A: J1.1, JP2.3 (B)
/QE1B: J1.2, JP3.3 (B)
/QE2A: J2.1, JP4.3 (B)
/QE2B: J2.2, JP5.3 (B)
GND: J1.4, J2.4, J3.4, J4.4, J5.4, J6.4, J7.3, J7.4, J8.4, J9.4, J10.2, J11.4, J12.4, J13.2, J14.4, Q1.1 (S), Q2.1 (S), Q3.1 (S), Q4.1 (S), Q5.1 (S), Q6.1 (S), Q7.1 (S), Q8.1 (S), Q9.1 (S)
unnamed: J3.2, Q1.3 (D)
unnamed: J4.2, Q2.3 (D)
unnamed: J5.2, Q3.3 (D)
unnamed: J6.2, Q4.3 (D)
unnamed: J8.2, Q5.3 (D)
unnamed: J9.2, Q6.3 (D)
unnamed: J11.2, Q7.3 (D)
unnamed: J12.2, Q8.3 (D)
unnamed: J14.2, Q9.3 (D)
VBUS: J1.3, J2.3, J10.1, JP1.1 (A)

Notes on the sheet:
RAW
RST
QE1
GND
QE2
1/TX
VCC
0/RX

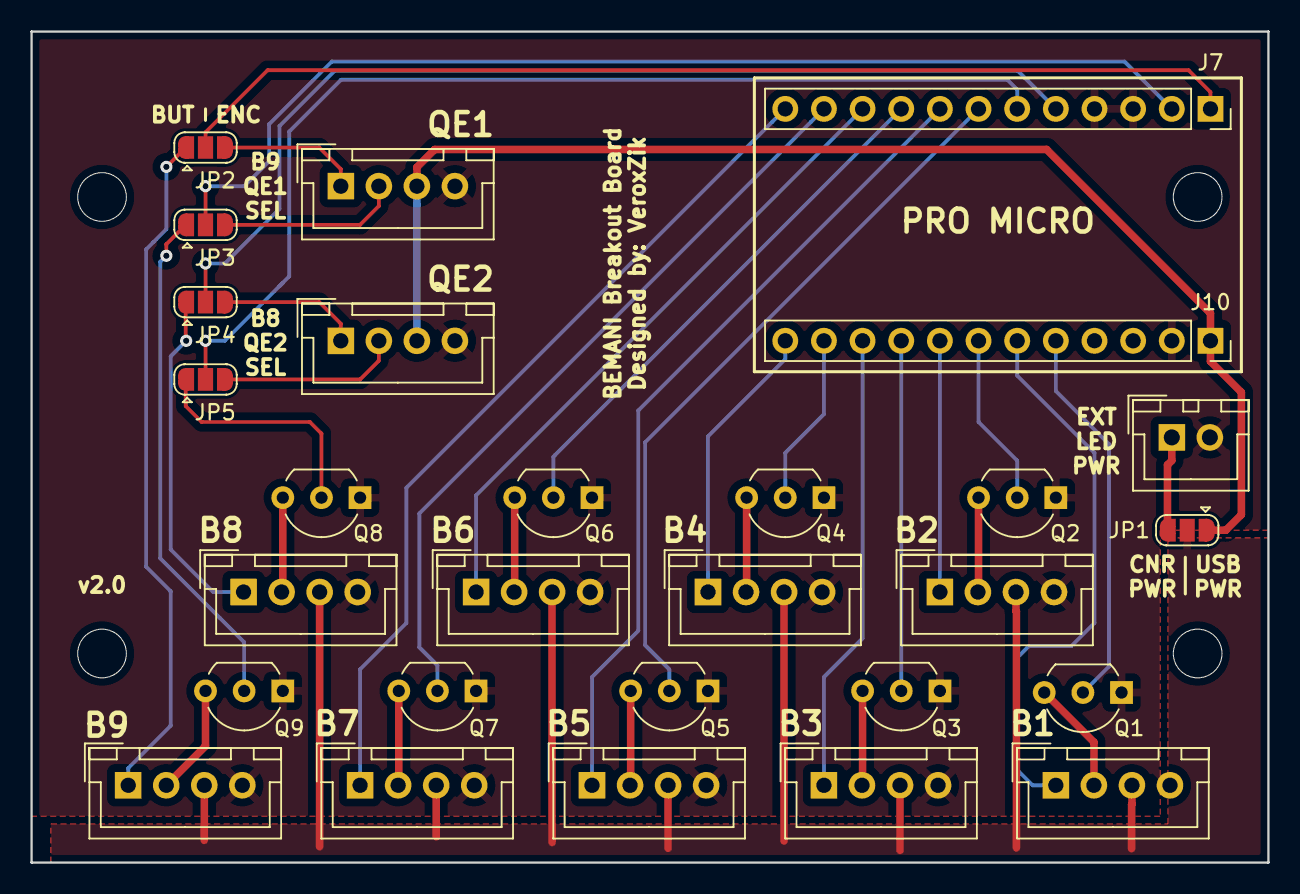
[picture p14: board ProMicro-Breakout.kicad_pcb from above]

Board: 2 copper layers, 81.3 x 54.6 mm, 32 parts (0 on the bottom side), 39 nets.

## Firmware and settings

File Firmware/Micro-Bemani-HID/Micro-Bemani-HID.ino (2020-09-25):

/* --- --- --- --- --- --- --- --- --- --- --- ---
    Micro / Pro Micro Bemani Code
   --- --- --- --- --- --- --- --- --- --- --- ---
   Code written for use with:
   https://github.com/veroxzik/bemani-arduino-boards

   Refer to Config.h for user-settable variables

   Licensed under GNU GPL v3.0

   --- --- --- --- --- --- --- --- --- --- --- --- */

#include "Config.h"
#include "Globals.h"
#include "Encoder.h"

#if defined(INPUT_KEYBOARDMOUSE)
#include <Mouse.h>
#include <Keyboard.h>
#elif defined(INPUT_JOYSTICK)
#include <Joystick.h>
#endif

// Encoders
extern uint8_t encoderPins[];
extern const uint16_t pulseCount;

Encoder *encoders[] = {
#if NUM_ENCODERS > 0
  new Encoder(pulseCount, encoderPins[0], encoderPins[1]),
#if NUM_ENCODERS > 1
  new Encoder(pulseCount, encoderPins[2], encoderPins[3])
#endif
#endif
};

// Buttons
extern uint8_t buttonPins[];
extern uint8_t numButtons;
#if defined(INPUT_JOYSTICK)
Joystick_ Joystick(JOYSTICK_DEFAULT_REPORT_ID, JOYSTICK_TYPE_GAMEPAD, numButtons, 0,
                   true, true, false, false, false, false, false, false, false, false, false);
#endif

#include "HIDLED.h"

// Lights
bool lightStatus[NUM_SINGLE_LED];

// SDVX LED Strip
#if defined(USE_SDVX_LED_STRIP)
#include "SdvxLedStrip.h"
SdvxLedStrip ledStrip;
#endif

void setup()
{
  Serial.begin(115200);

#if defined(INPUT_JOYSTICK)
  // Setup Joystick
  Joystick.setXAxisRange(-(int16_t)pulseCount / 2, (int16_t)pulseCount / 2);
  Joystick.setYAxisRange(-(int16_t)pulseCount / 2, (int16_t)pulseCount / 2);
  Joystick.begin(false);
  Joystick.setXAxis(0);
  Joystick.setYAxis(0);
#elif defined(INPUT_KEYBOARDMOUSE)
  Mouse.begin();
  Keyboard.begin();
#endif

  // Setup Encoders
#if NUM_ENCODERS > 0
  encoders[0]->updateState();
#if NUM_ENCODERS > 1
  encoders[1]->updateState();
#endif
#endif

  // It's not possible to attach interrupts (well) inside classes, unfortunately
#if NUM_ENCODERS > 0
  attachInterrupt(digitalPinToInterrupt(encoderPins[0]), processEncoder0, CHANGE);
  attachInterrupt(digitalPinToInterrupt(encoderPins[1]), processEncoder0, CHANGE);
#if NUM_ENCODERS > 1
  attachInterrupt(digitalPinToInterrupt(encoderPins[2]), processEncoder1, CHANGE);
  attachInterrupt(digitalPinToInterrupt(encoderPins[3]), processEncoder1, CHANGE);
#endif
#endif

  // Setup Buttons
  for (int i = 0; i < numButtons; i++)
    pinMode(buttonPins[i], INPUT_PULLUP);

  // Setup Lights
  for (int i = 0; i < NUM_SINGLE_LED; i++)
    pinMode(ledPins[i], OUTPUT);
}

void loop()
{
  // Read / set buttons
  for (int i = 0; i < numButtons; i++)
  {
    uint8_t buttonState = digitalRead(buttonPins[i]);
    if (buttonState)
    {
#if defined(INPUT_KEYBOARDMOUSE)
      Keyboard.release(buttonKeys[i]);
#elif defined(INPUT_JOYSTICK)
      Joystick.releaseButton(i);
#endif
    }
    else
    {
#if defined(INPUT_KEYBOARDMOUSE)
      Keyboard.press(buttonKeys[i]);
#elif defined(INPUT_JOYSTICK)
      Joystick.pressButton(i);
#endif
    }

    // Set reactive lights
#if !defined(HID_LIGHTS)
    digitalWrite(ledPins[i], buttonState ? LOW : HIGH);
#endif
  }

  // Write analog values
#if defined(INPUT_JOYSTICK)
#if NUM_ENCODERS > 0
#if NUM_ENCODERS > 1
  Joystick.setXAxis(encoders[0]->getPosition());
#endif
  Joystick.setYAxis(encoders[1]->getPosition());
#endif
#elif defined(INPUT_KEYBOARDMOUSE)
  signed char mouseX = 0, mouseY = 0;
#if NUM_ENCODERS > 0
#if NUM_ENCODERS > 1
  mouseX = encoders[0]->getDelta() * MOUSE_MULTIPLIER;
#endif
  mouseY = encoders[1]->getDelta() * MOUSE_MULTIPLIER;
#endif
  Mouse.move(mouseX, mouseY, 0);
#endif

#if defined(INPUT_JOYSTICK)
  Joystick.sendState();
#endif

  // Set lights
#if defined(HID_LIGHTS)
  for (int i = 0; i < NUM_SINGLE_LED; i++)
    digitalWrite(ledPins[i], lightStatus[i]);
#endif

#if defined(USE_SDVX_LED_STRIP)
  noInterrupts();
  ledStrip.update();
  interrupts();
#endif
}

void processEncoder0()
{
  bool dir = encoders[0]->updateEncoder();
#if defined(USE_SDVX_LED_STRIP)
  if (SDVX_REVERSE_KNOB)
    ledStrip.setRightActive(SDVX_DIRECTION_RIGHT ? !dir : dir);
  else
    ledStrip.setLeftActive(SDVX_DIRECTION_LEFT ? !dir : dir);
#endif
}

void processEncoder1()
{
  bool dir = encoders[1]->updateEncoder();
#if defined(USE_SDVX_LED_STRIP)
  if (SDVX_REVERSE_KNOB)
    ledStrip.setLeftActive(SDVX_DIRECTION_LEFT ? !dir : dir);
  else
    ledStrip.setRightActive(SDVX_DIRECTION_RIGHT ? !dir : dir);
#endif
}

void light_update(SingleLED* single_leds, RGBLed* rgb_leds)
{
  for (int i = 0; i < NUM_SINGLE_LED; i++) {
    lightStatus[i] = single_leds[i].brightness > 0 ? true : false;
  }
  //  for (int i = 0; i < NUM_RGB_LED; i++) {
  //    // Do nothing
  //  }
}

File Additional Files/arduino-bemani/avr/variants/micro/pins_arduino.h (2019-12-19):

/*
  pins_arduino.h - Pin definition functions for Arduino
  Part of Arduino - http://www.arduino.cc/

  Copyright (c) 2007 David A. Mellis

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
  You should have received a copy of the GNU Lesser General
  Public License along with this library; if not, write to the
  Free Software Foundation, Inc., 59 Temple Place, Suite 330,
  Boston, MA  02111-1307  USA
*/

#include "../leonardo/pins_arduino.h"

#undef TXLED0
#undef TXLED1
#undef RXLED0
#undef RXLED1
#undef TX_RX_LED_INIT

#define TXLED0			PORTD &= ~(1<<5)
#define TXLED1			PORTD |= (1<<5)
#define RXLED0			0
#define RXLED1			0
#define TX_RX_LED_INIT	DDRD |= (1<<5), DDRB |= (1<<0), TXLED0, RXLED0

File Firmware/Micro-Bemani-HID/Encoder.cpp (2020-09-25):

#include "Encoder.h"

Encoder::Encoder(uint16_t maxRange, uint8_t pinA, uint8_t pinB)
{
  position = 0;
  range = maxRange;
  pins[0] = pinA;
  pins[1] = pinB;
  pinMode(pins[0], INPUT_PULLUP);
  pinMode(pins[1], INPUT_PULLUP);
}

void Encoder::updateState()
{
  state = GET_ENCODER(pins[0], pins[1]);
}

bool Encoder::updateEncoder()
{
  bool dir = false;
  uint8_t newState = GET_ENCODER(pins[0], pins[1]);
  int16_t tempPosition = position;
  uint8_t tempState = state | (newState << 2);
  state = newState;
  switch (tempState) {
    case 1: case 7: case 8: case 14:
      position++;
      delta++;
      dir = true;
      break;
    case 2: case 4: case 11: case 13:
      position--;
      delta--;
      dir = false;
      break;
    case 3: case 12:
      position += 2;
      delta += 2;
      dir = true;
      break;
    case 6: case 9:
      position -= 2;
      delta -= 2;
      dir = false;
      break;
  }
  if (position < -(int16_t)range / 2)
    position += (int16_t)range;
  else if (position > (int16_t)range / 2)
    position -= (int16_t)range;

  return dir;
}

int16_t Encoder::getDelta()
{
  int16_t tempDelta = delta;
  delta = 0;
  return tempDelta;
}

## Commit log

2019-10-27 Initial Commit
    Includes:
    Pro Micro Single LED board
    Pro Micro RGB board
    Micro Single LED board
    [Micro-Breakoutout-B.Cu.gbr, Micro-Breakoutout-B.Mask.gbr, Micro-Breakoutout-B.Paste.gbr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]
2019-10-27 Fixed broken trace on Micro Breakout
    [Micro-Breakoutout-B.Cu.gbr, Micro-Breakoutout-B.Mask.gbr, Micro-Breakoutout-B.Paste.gbr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]
2019-10-27 Fixed Micro-Breakout filenames
    [Micro-Breakout-B.Cu.gbr, Micro-Breakout-B.Mask.gbr, Micro-Breakout-B.Paste.gbr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]
2019-10-27 Adds Micro Breakout RGB version
    [Micro-Breakout+RGB-B.Cu.gbr, Micro-Breakout+RGB-B.Mask.gbr, Micro-Breakout+RGB-B.Paste.gbr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]
2020-01-31 Fixed Encoder
    Was broken for PPR > 255 / in general
    [Encoder.cpp, Micro-Bemani-HID.ino]
2020-01-31 Fixed Lights
    Forgot to set pins to output
    [Micro-Bemani-HID.ino]
2020-01-31 Added Micro RGB pinout to code, fixed lights (again)
    [Micro-Bemani-HID.ino]
2020-02-21 Update both micro boards to v1.1
    Fixes 5V on the LED connector
    Adds pinout labels for Encoder / Button connectors
    [Micro-Breakout+RGB-B_Cu.gbr, Micro-Breakout+RGB-B_Mask.gbr, Micro-Breakout+RGB-B_Paste.gbr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]
2020-05-31 Update Micro-RGB to v1.2
    This shifts the SS and MISO pins to B9 in an attempt to consolidate potentially nonfunctional pins while using the SPI port for RGB functionality.
    [Micro-Breakout+RGB-B.Cu.gbr, Micro-Breakout+RGB-B.Mask.gbr, Micro-Breakout+RGB-B.Paste.gbr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]
2020-09-25 Updated Firmware, Added schematic PDF
    Adds support for the Turbocharger+ LED boards
2020-09-25 Adds Arduino SPI library
2023-02-12 Update ProMicro-Breakout board.
    [ProMicro-Breakout-B.Cu.gbr, ProMicro-Breakout-B.Mask.gbr, ProMicro-Breakout-B.Paste.gbr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]
2023-02-12 Update ProMicro-Breakout+RGB board.
    [ProMicro-Breakout+RGB-B.Cu.gbr, ProMicro-Breakout+RGB-B.Mask.gbr, ProMicro-Breakout+RGB-B.Paste.gbr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]
2023-02-12 Update MicroBreakout+RGB board.
    [Micro-Breakout+RGB-B_Cu.gbr, Micro-Breakout+RGB-B_Mask.gbr, Micro-Breakout+RGB-B_Paste.gbr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]
2023-02-13 Update Micro-Breakout board.
    [Micro-Breakout-B_Cu.gbr, Micro-Breakout-B_Mask.gbr, Micro-Breakout-B_Paste.gbr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]
2023-02-13 Add overall board README and move all old boards to archive.
